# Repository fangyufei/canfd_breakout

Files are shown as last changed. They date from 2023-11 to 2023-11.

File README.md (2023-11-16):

# canfd_breakout
 
Small footprint can-fd breakout board. Mainly used 0805 smd parts.
Arduino libray acan2517fd works well.

https://github.com/pierremolinaro/acan2517FD

IO Voltage Vio can be set via 0Ohm Resistor R2=>3V3 or R3=>5V.
Even when Vio is set to 3V3, the board (the transceiver) needs 5V supply for proper CAN sending.

The 40MHz crystal can be replaced by a 20MHz or 4MHz crystal. However this affects CAN timing parameters in SW.

PCB:






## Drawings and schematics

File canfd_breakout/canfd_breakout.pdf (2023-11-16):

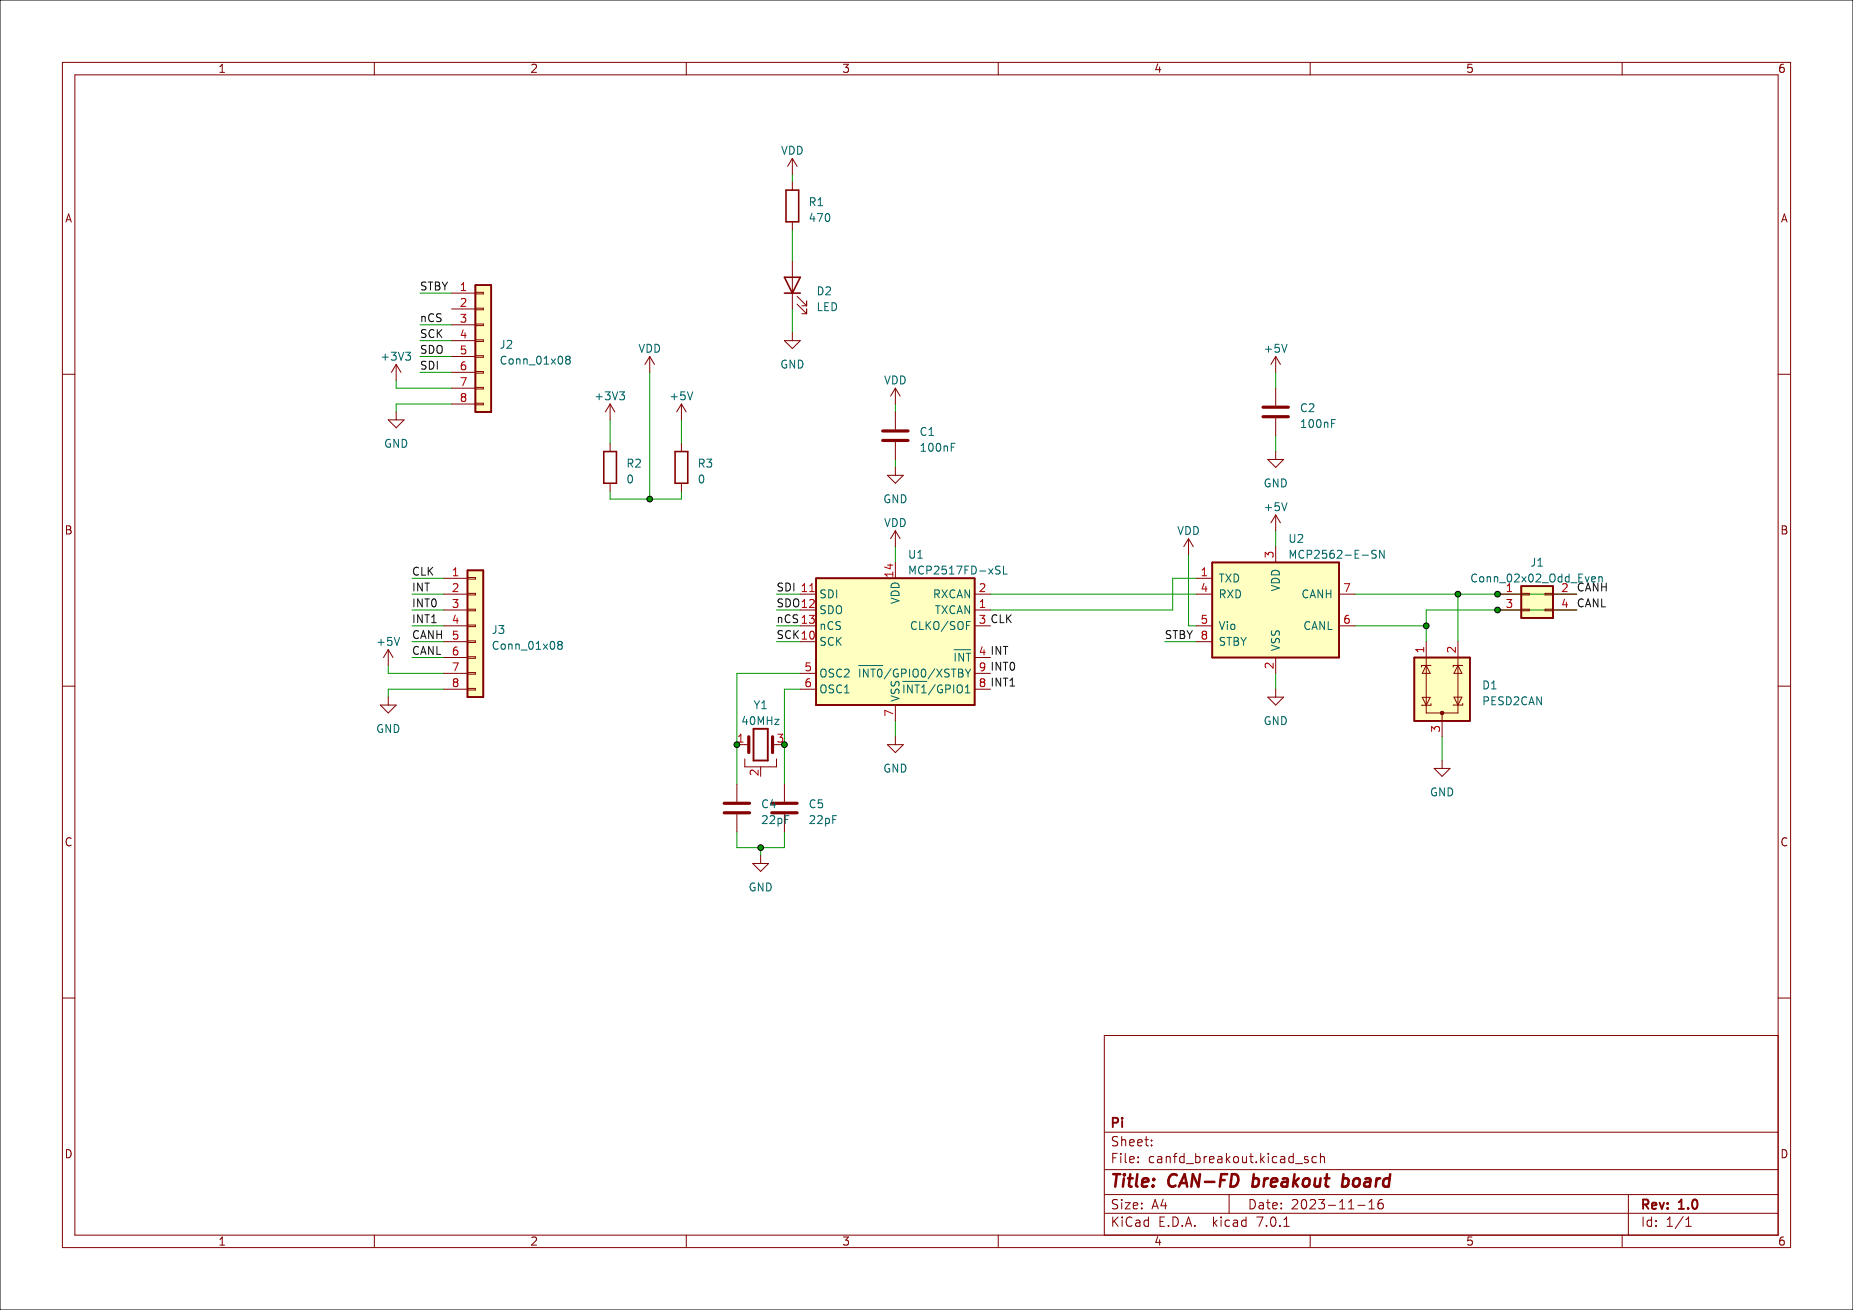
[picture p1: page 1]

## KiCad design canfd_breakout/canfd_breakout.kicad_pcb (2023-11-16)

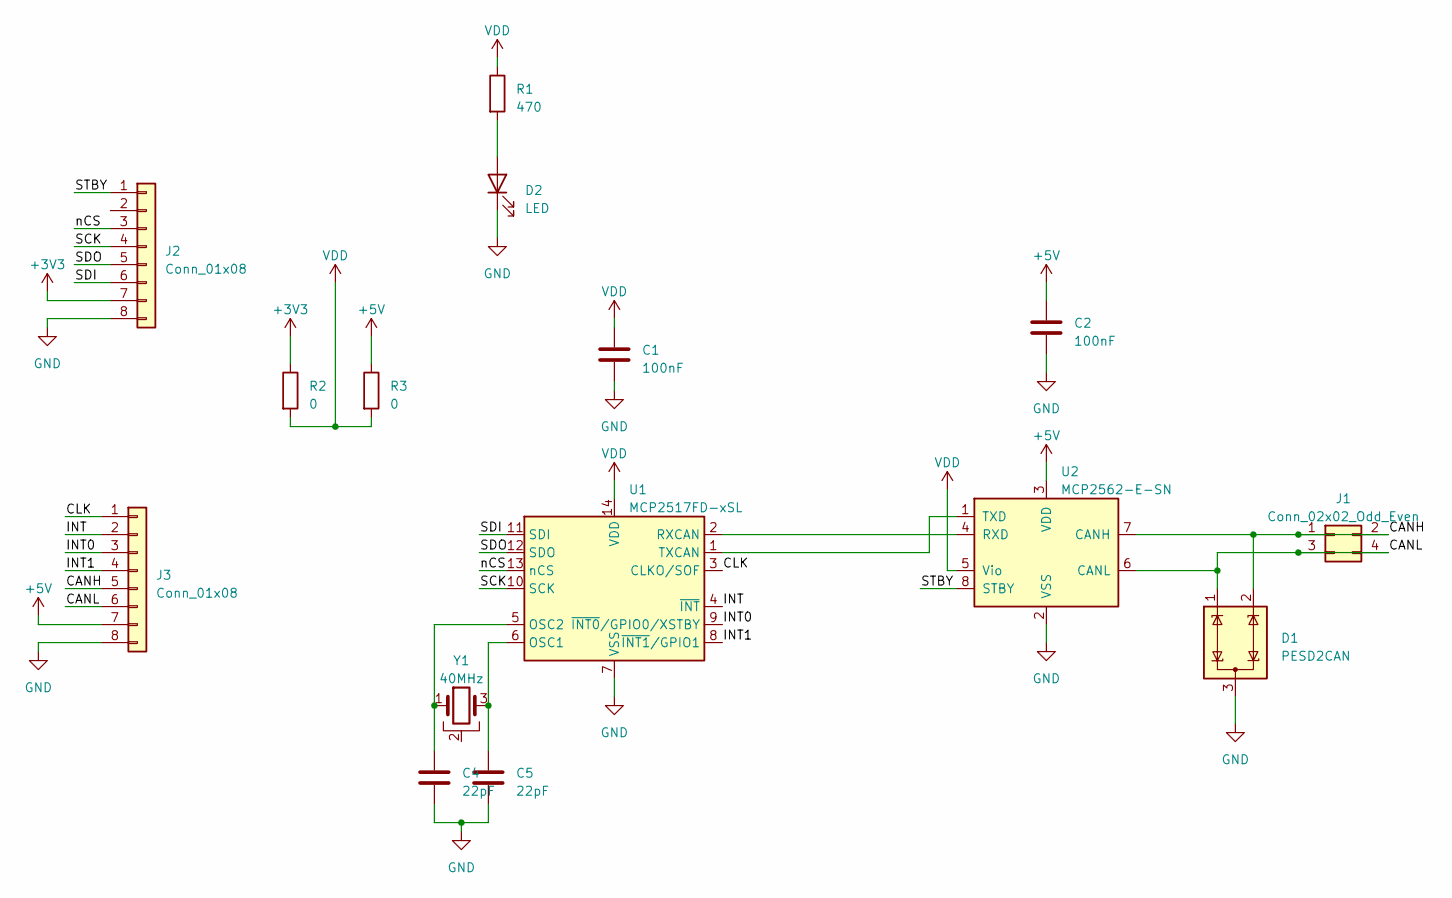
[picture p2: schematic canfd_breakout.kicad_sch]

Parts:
C1, C2: 100nF; C_0805_2012Metric_Pad1.18x1.45mm_HandSolder
C4, C5: 22pF; C_0805_2012Metric_Pad1.18x1.45mm_HandSolder
D1: PESD2CAN; SOT-23
D2: LED; LED_0805_2012Metric_Pad1.15x1.40mm_HandSolder
J1: Conn_02x02_Odd_Even; PinHeader_2x02_P2.54mm_Vertical
J2, J3: Conn_01x08; PinHeader_1x08_P2.54mm_Vertical
R1: 470; C_0805_2012Metric_Pad1.18x1.45mm_HandSolder
R2, R3: 0; R_0805_2012Metric_Pad1.20x1.40mm_HandSolder
U1: MCP2517FD-xSL; SOIC-14_3.9x8.7mm_P1.27mm
U2: MCP2562-E-SN; SOIC-8_3.9x4.9mm_P1.27mm
Y1: 40MHz; Crystal_SMD_3225-4Pin_3.2x2.5mm

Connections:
+3V3: J2.7, R2.1
+5V: C2.1, J3.7, R3.1, U2.3 (VDD)
/CANH: D1.2 (K), J1.1, J1.2, J3.5, U2.7 (CANH)
/CANL: D1.1 (K), J1.3, J1.4, J3.6, U2.6 (CANL)
/CLK: J3.1, U1.3 (CLKO/SOF)
/INT: J3.2, U1.4 (~INT)
/INT0: J3.3, U1.9 (~INT0/GPIO0/XSTBY)
/INT1: J3.4, U1.8 (~INT1/GPIO1)
/SCK: J2.4, U1.10 (SCK)
/SDI: J2.6, U1.11 (SDI)
/SDO: J2.5, U1.12 (SDO)
/STBY: J2.1, U2.8 (STBY)
/nCS: J2.3, U1.13 (nCS)
GND: C1.2, C2.2, C4.2, C5.2, D1.3 (A), D2.1 (K), J2.8, J3.8, U1.7 (VSS), U2.2 (VSS)
unnamed: D2.2 (A), R1.2
unnamed: C5.1, U1.6 (OSC1), Y1.3
unnamed: C4.1, U1.5 (OSC2), Y1.1
unnamed: U1.2 (RXCAN), U2.4 (RXD)
unnamed: U1.1 (TXCAN), U2.1 (TXD)
VDD: C1.1, R1.1, R2.2, R3.2, U1.14 (VDD), U2.5 (Vio)

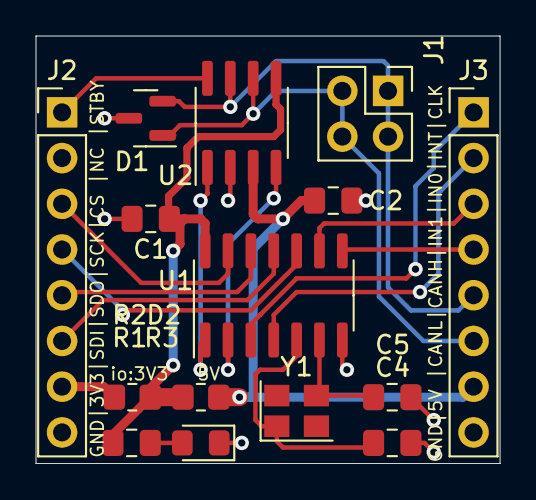
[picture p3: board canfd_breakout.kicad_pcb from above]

Board: 2 copper layers, 25.8 x 23.7 mm, 15 parts (0 on the bottom side), 20 nets.
